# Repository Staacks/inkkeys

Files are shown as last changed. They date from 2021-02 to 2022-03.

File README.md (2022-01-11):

# inkkeys
Details and instructions can be found on https://there.oughta.be/a/macro-keyboard

In contrast to most of my other projects, I decided to put this into its own repository as it is slightly more complex and I am hoping for community contributions.

If you have pull-requests, bug reports or want to contribute new case designs, please do not hesitate to open an issue. For generic discussions, "show and tell" and if you are looking for support for something that is not a problem in the code here, I would recommend [r/thereoughtabe on reddit](https://www.reddit.com/r/thereoughtabe/).

<a href="https://www.buymeacoffee.com/there.oughta.be" target="_blank">Buy Me A Coffee</a>

## Common problems

### Display revision 2
Apparently, the original design used revision 1 of the display, while many newly ordered version are revision 2. There are a few differences and thankfully, [Corky402 made a good list of required changes on Reddit](https://www.reddit.com/r/arduino/comments/l4wxxf/the_hardware_is_assembled_and_passed_all_tests/gqovq1j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). Here is an excerpt of the original post for reference:
>If you want to test your display hooked to a Arduino or Raspberry Pi you need to run examples for the epd2in9_V2 not the epd2in9.
>
>To get this awesome project working there is no need to make any alterations to the PCB, just simply plumb the Waveshare up on the connectors as I describe, not as per Sebastian's original post.
>
>PCB Pin Waveshare wiring loom
>
>+5v Grey
>
>GND Brown
>
>DIN Blue
>
>CLK Yellow
>
>CS Orange
>
>DC Green
>
>RST Purple
>
>BUSY White
>
>In short you are swapping the RST & BUSY lines on the PCB.
>
>Next, go to your Arduino sketch. This is for the hardware-test script. Enable line numbering and go to line 43 which reads -
>
```c
GxEPD2_290 display(/*CS=*/ PIN_CS, /*DC=*/ PIN_DC, /*RST=*/ PIN_RST, /*BUSY=*/ PIN_BUSY);
```
>
>Change this to -

```c
GxEPD2_290_T94 display(/*CS=*/ PIN_CS, /*DC=*/ PIN_DC, /*RST=*/ PIN_RST, /*BUSY=*/ PIN_BUSY);
```

>Then go to settings.h
>
>Lines 2 - 7 need to be altered so change that section of code as follows -
```c
const byte PIN_DIN = 16;
const byte PIN_CLK = 15;
const byte PIN_CS = 19;
const byte PIN_DC = 18;
const byte PIN_RST = 10;
const byte PIN_BUSY = 14;
```
>
>The sketch will then compile and when uploaded to the board you will get the Waveshare drawing all sorts of Austin Powers time machine circles that make your eyes spin! 

## Gallery

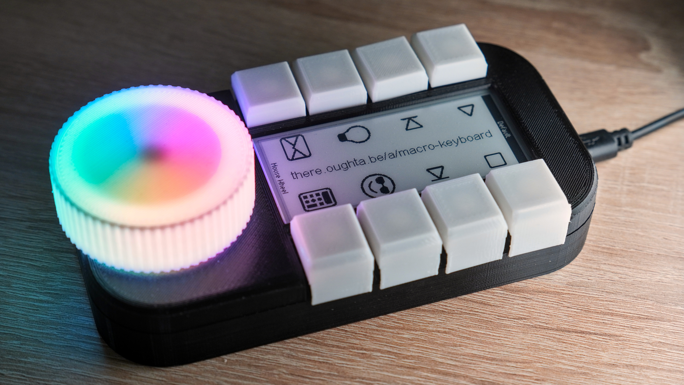
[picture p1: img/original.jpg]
Original design Original design as presented on there.oughta.be with the 3d printing files from this repository.

Original design as presented on there.oughta.be with the 3d printing files from this repository.

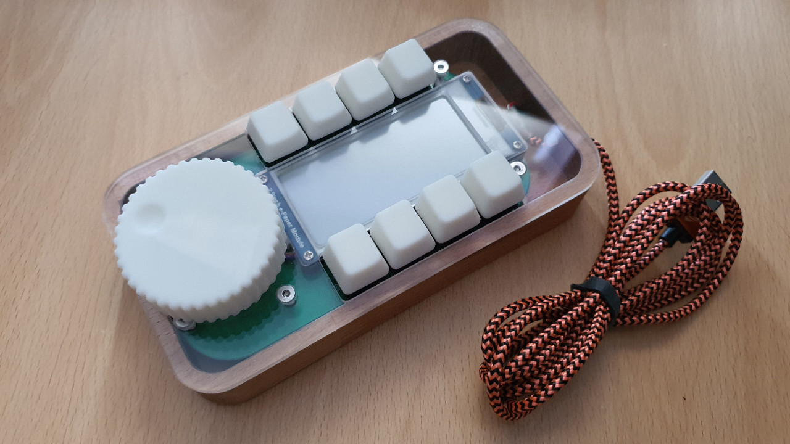
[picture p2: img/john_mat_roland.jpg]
Original design Design by John, Mat and Roland from the UK. The case was CNC milled from beech with a similarly machined clear perspex lid.

Design by John, Mat and Roland from the UK. The case was CNC milled from beech with a similarly machined clear perspex lid. You can find the knob with finger dimple by Roland Irving in the 3dprint folder as know_with_dimple.stl.

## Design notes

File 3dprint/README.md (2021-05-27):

# 3d models

All STLs are based on the same [Blender](https://www.blender.org/) file I used to create the animations in the video. The model in the blend file is based on a 3d model exported from KiCad, which I converted using FreeCAD. So, most of the components are from the KiCad libraries while I got the Pro Micro from the [Spark Fun KiCad Libraries](https://github.com/sparkfun/SparkFun-KiCad-Libraries) combined with a [3d model by Andrew Whitham](https://grabcad.com/library/arduino-pro-micro-1) for the Pro Micro.

The knob version with a finger dimple (know_with_dimple.stl) is by Roland Irving.

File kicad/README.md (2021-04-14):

# Alternative layouts and PCB designs

Modifications by user are linked below:
* [SMD version by dschiedsch](https://github.com/dschiedsch/inkkeys) Similar to the orignal, but LEDs, resistors and capacitors are SMD components.

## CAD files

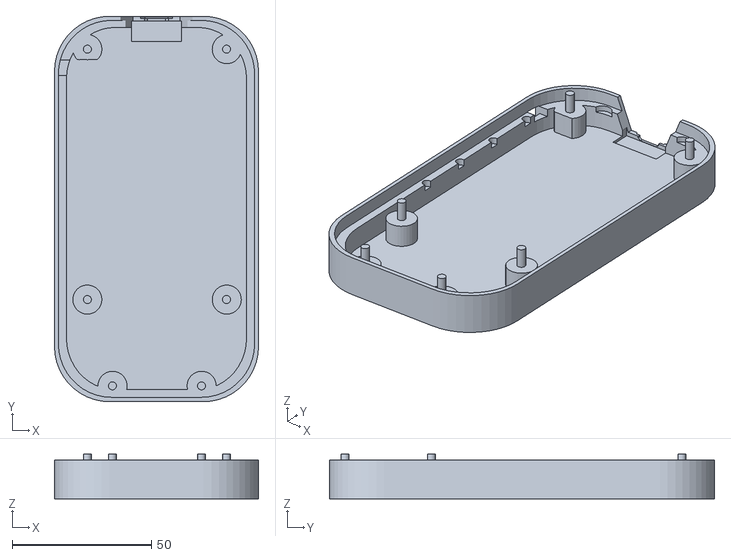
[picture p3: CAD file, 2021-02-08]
3dprint/bottom.stl
73.3 x 138.5 x 16.1

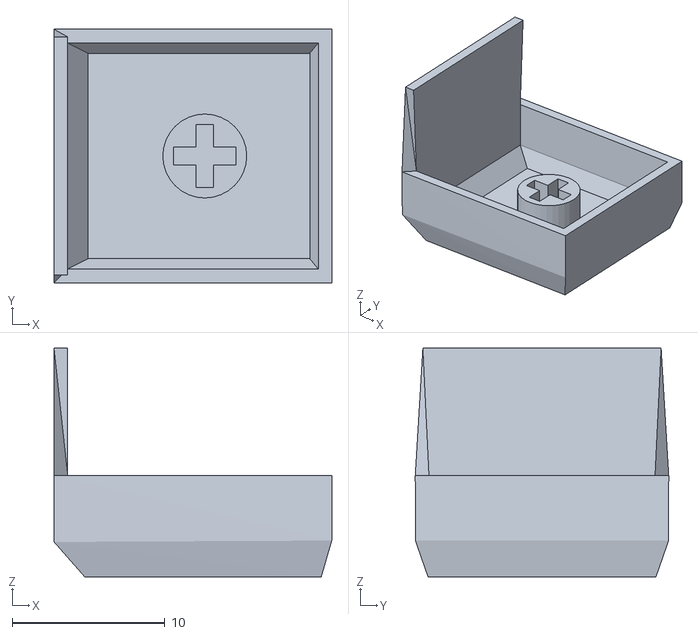
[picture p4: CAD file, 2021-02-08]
3dprint/key.stl
18.2 x 16.6 x 15.0

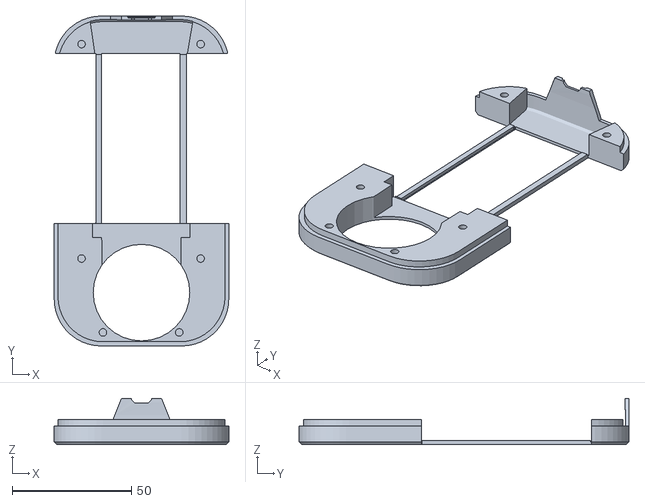
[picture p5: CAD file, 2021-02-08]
3dprint/top.stl
73.3 x 138.5 x 19.4

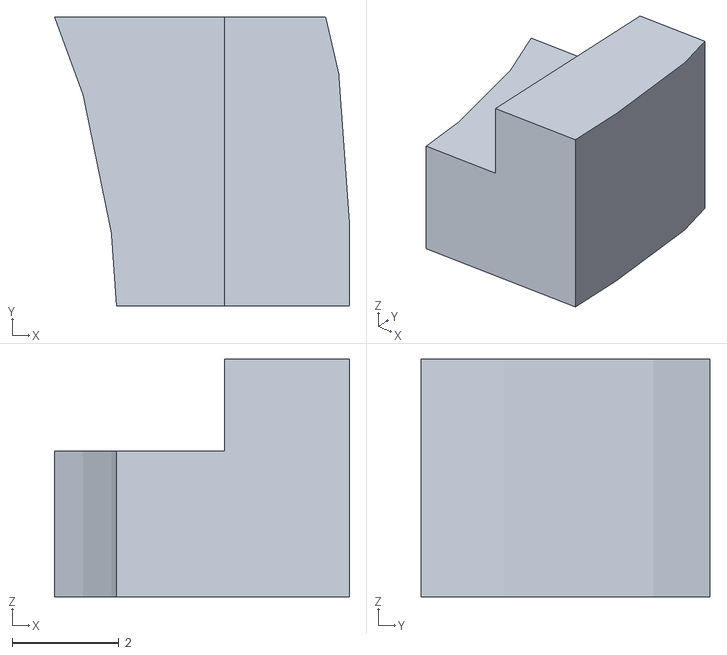
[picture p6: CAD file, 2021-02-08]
3dprint/debug-plug.stl
5.53 x 5.42 x 4.46

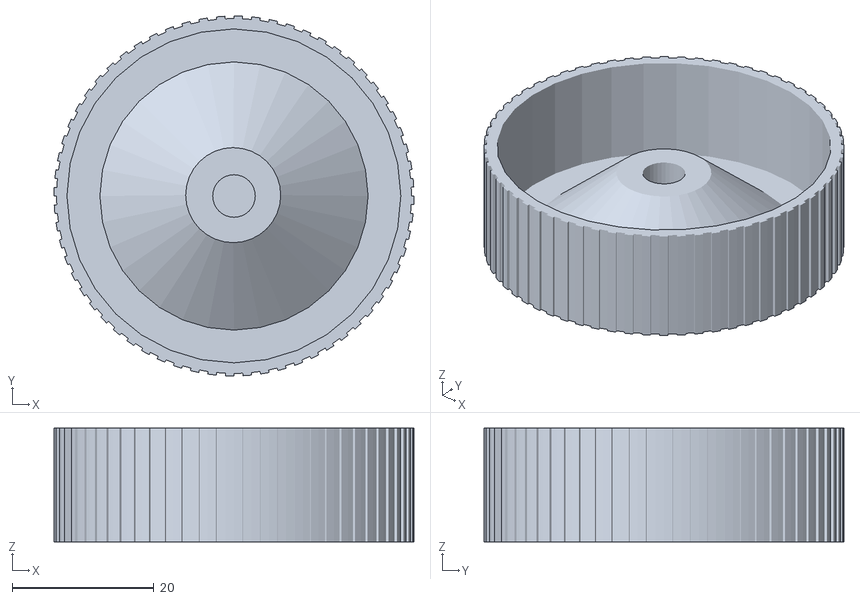
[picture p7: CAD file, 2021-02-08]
3dprint/knob.stl
50.7 x 50.7 x 16.1

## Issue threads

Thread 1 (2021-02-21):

Request: Gerber Files for Other PCB Services?

Extra-Fox, 2021-02-21:
Hi, I am totally digging this project and am eager to try my hand at building one.

Being an absolute hack when it comes to PCB software, would it be possible for you to create some Gerber files of your PCB design? I tried plotting it from KiCAD, but I wasn't getting copper layers that JLCPCB recognized.

Staacks, 2021-02-23:
Hm... Not sure if it will help if I export them. I ordered my PCB from aisler.net where I uploaded the KiCad files, so I have no starting point to export them any differently than you did. Are there any naming conventions from JLCPCB? I am quite sure that I had to rename a layer or two to match the aisler naming conventions, so maybe it is as simple as naming the layers according to their suggestions.

Extra-Fox, 2021-02-23:
Okay, bear with me here because my skill set here barely exists.

But it looks like they were looking for two layers named *.cu. Which didn't appear when I tried plotting from KiCAD (I downloaded and installed it for this)

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

And I was following these instructions here: https://support.jlcpcb.com/article/44-how-to-export-kicad-pcb-to-gerber-files

So if it's simply a naming convention in that case, I'd be happy to go into the files I have locally and change that, however I'd probably need your guidance on the conversion key.

Staacks, 2021-02-23:
Ah, I see. The "F.Cu" and "B.Cu" are just named "Front" and "Back" in my file. And now that I checked it I realize that this was not my idea but I started with a template from Aisler.

You might want to compare the manufacturing tolerances of Aisler and JLCPCB to see if there is something you need to look out for. Since I used the Aisler rules, some distance could be too small for other services, although I would not expect it as there is nothing too fancy about this design.

Extra-Fox, 2021-02-23:
Okay, I'll do that, thank you for the heads up and the guidance.

If anything, I can order from Aisler, but given my location it's generally less expensive for me to use JLCPCB. However, I do want this to work so maybe it's just safer to use Aisler.

Staacks, 2021-02-23:
Yeah, I have no reason to push Aisler - it is just the one I new and happened to use here. This is also the first PCB I designed, but I have ordered from Aisler before in the context of a project from work (in this case the PCB was designed by my PhD student who has done a few PCBs before). To us they are the most local manufacturer (we could literally walk across the border to their headquarter), so I started there without comparing manufacturers a lot.

However, the thing that made me stick with Aisler at least for this first project was that they have a render guarantee. So, I just upload the KiCad file and their system renders a preview of the PCB and they guarantee that the manufactured PCB will match that preview. For me as a beginner this eliminated exactly the "are the gerber files correct?" uncertainty. I will probably try other sources as well on simpler future projects, because Aisler is indeed rather expensive.

Extra-Fox, 2021-02-23:
I totally understand and I didn't get that impression. Local is always good. We have OSHPark which might be considered local, but is still half way across the country from me. Their prices get rather high as well depending on the board.

I've never even designed a board before, just sent those designed by others off to be produced. So, I'm not sure I'm brave enough to take the leap you did, but maybe one day. So far I've just clumsily hand wired any projects without boards.

Extra-Fox, 2021-02-24:
Well, I figured it out. I got it working with OSHPark and with JLCPCB. Unfortunately OSHPark's price was over $70USD so that was a non-starter. JLCPCB was able to do it, with a black circuit board and ENIG-ROHS coating for $35USD shipped.

Staacks, 2021-02-24:
Well, that is not that much cheaper, but it is a rather large PCB.

Extra-Fox, 2021-02-24:
No, probably less than having it made in DE and shipped here, but not a lot less. I'm more familiar with using JLCPCB though so it's a comfort level thing I suppose.

Extra-Fox, 2021-03-16:
It sure is a nice board.
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

Staacks, 2021-03-19:
I really need to try other manufacturers - Just for that black finish :)

x4FF3, 2021-06-11:
my JLCPCB order was 16$ for 5 PCBs :) shipped to germany

WiBla, 2022-01-26:
Hello, I'm also looking forward building my own macropad !

@x4FF3 would you be so kind as to provide the gerber files you used ?
Thanks in advance !

Closed 2021-02-23.

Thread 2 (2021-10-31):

Capacitors for neo pixels

drobertwilcox, 2021-10-31:
Hello Sebastian,

I found your project through a hack a day blog post, https://hackaday.com/2021/02/18/dynamic-macro-keyboard-controls-all-the-things/, and I am certainly interested in trying to build one.  I have not completely reviewed the circuit, but I did see that the RGB neo pixel LED modules do not have a decoupling capacitor.  This could cause flashing, browning out, general misbehaving of the LED device.  I am currently installing ki-cad to look at the circuit design and layout.  I am bringing this up because I was thinking about modifying the layout and adding a string of addressable RGB under the key caps, because more RGB is always better! Though I will have to look at the power consumption of the devices in total to ensure that it stays USB compatible with no need of an external power source. This part may be the part of choice for individual key RGB https://kprepublic.com/products/xd-halo-rgb-light-control-pcb-soft-lighting-light-diffuser-circle-light-for-mechanical-keyboard-cospad-xd60-64-75-84-96-40-68

Staacks, 2021-10-31:
Yes, I definitely forgot those. I am quite new to these designs and learned about this issue after I finished the project. Luckily, I had no issues so far, but as far as I can tell from my research, the cheap THT RGB LEDs in my design are even more susceptible to such issues than the typical WS2812b ones.

Let me know about your project when it is ready. If you intent to share, I will happily link to the improved version in the readme of my repository version or directly add it if you don't want to publish it as a fork yoursef.

drobertwilcox, 2021-10-31:
I am new to GIThub, please excuse me if I don't know the processes that are in place to fork a project.  I will be exploring options for the RGB key switches.  Maybe the key switches with the 4 holes for the LED to pass through would be a better choice for anchoring the key to the board: https://www.amazon.com/Transparent-Switches-Mechanical-Keyboard-Compatible/dp/B07K7LJNLR?th=1 I don't know if the 5mm LED will fit inside.
I will let you know what I come up with, and also I may need some time to learn how to use github.

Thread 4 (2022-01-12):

LED Pin Spacing and Ground Plane

Rudis1261, 2022-01-12:
I order 5 boards from PCBway and I am super happy that they came out really great. But one of the issues I was having is definitely the pin spacing of the LEDs, it's quite a pain. I think most people would be happy to print a 3mm or so ring spacer and rather use 2.54mm pitch, with the legs slightly bent. I kinda trashed one of my boards just because of that issue.

This raised something else, which may need improvement. The ground plane is massive :scream:, my poor little soldering iron could not heat it fast enough to use a wick as suggested to clear out excess solder.

I wonder if the ground plane could have an isolation ring around the circuit to reduce the ground plane, and make it easier to heat up. Basically, all the heat is transferring into that entire PCB plane at the moment.

Not so much as an issue, but a quality of life on both

Staacks, 2022-01-14:
I am happy to add this to the repository if someone tries this modification and confirms that it works.

Regarding the GND plane, I do not particularly recall problems while soldering, but for anyone who is worried about this, there is an easy solution: If you select the ground plane in KiCad and go to its properties, there is an option "pad connections" which is already set to "thermal reliefs". So, at the moment, all pads only use thin spokes to connect to the ground plane to alleviate this exact problem. If you want to reduce the thermal coupling further, you can modify the settings below this to create thinner spokes or increase the clearance. You can also set this individually for each pad than for the entire plane.

Rudis1261, 2022-01-14:
That's awesome thanks Sebastian! I will probably have it made in future
again as the project matures.

I will also definitely try your suggestion next time before I generate the
grbl files.

Cheers,
Rudi

On Fri, Jan 14, 2022 at 1:33 PM Sebastian Staacks ***@***.***>
wrote:

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

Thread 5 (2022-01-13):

Can't seem to get the python app running

Rudis1261, 2022-01-13:
I run windows 10, and it seems it's not quite working as expected. I first ran into an issue where win32gui wasn't available, and resolved that by installing `pip install pywin32`

Then I tried launching it, but next it failed at a pulse audio import in modes.py. Which from what I understand should only be available in linux.

```
Traceback (most recent call last):
  File "./controller.py", line 9, in <module>
    from modes import *          #Definitions of the hotkey functions in different "modes"
  File "C:\Users\Rudi\Documents\Github\inkkeys\python-controller\modes.py", line 23, in <module>
    import pulsectl                                  # Get volume level in Linux, pip3 install pulsectl
  File "C:\Users\Rudi\AppData\Local\Programs\Python\Python37\lib\site-packages\pulsectl\__init__.py", line 4, in <module>
    from . import _pulsectl
  File "C:\Users\Rudi\AppData\Local\Programs\Python\Python37\lib\site-packages\pulsectl\_pulsectl.py", line 684, in <module>
    pa = LibPulse()
  File "C:\Users\Rudi\AppData\Local\Programs\Python\Python37\lib\site-packages\pulsectl\_pulsectl.py", line 636, in __init__
    p = CDLL(ctypes.util.find_library('libpulse') or 'libpulse.so.0')
  File "C:\Users\Rudi\AppData\Local\Programs\Python\Python37\lib\ctypes\__init__.py", line 356, in __init__
    self._handle = _dlopen(self._name, mode)
OSError: [WinError 126] The specified module could not be found
```

I then commented out the pulse audio import which got me to where I am now.

My device is COM20, and when I start it, it does this:
```$ ./controller.py
https://there.oughta.be/a/macro-keyboard
I will try to stay connected. Press Ctrl+c to quit.
Connecting to  COM20 .
Requesting device info...
Header found. Waiting for infos...
End of info received.
Testmode:  False
Number of LEDs:  10
Display width:  128
Display height:  296
Rotation circle steps:  20
Connected to  COM20 .
Error:  <class 'AttributeError'>
I will retry in three seconds...
Connecting to  COM20 .
Serial error:  could not open port 'COM20': PermissionError(13, 'Access is denied.', None, 5)
I will retry in three seconds...
Connecting to  COM20 .
Serial error:  could not open port 'COM20': PermissionError(13, 'Access is denied.', None, 5)
I will retry in three seconds...
Connecting to  COM20 .
Serial error:  could not open port 'COM20': PermissionError(13, 'Access is denied.', None, 5)
I will retry in three seconds...
Connecting to  COM20 .
Serial error:  could not open port 'COM20': PermissionError(13, 'Access is denied.', None, 5)
I will retry in three seconds...
Connecting to  COM20 .
```

Any advice / suggestions would be welcome.

Staacks, 2022-01-16:
Unfortunately, I do not have a Windows machine that I can easily use to test, so I can only offer my experience of a little mistake I sometimes made during development: If you have the Arduino IDE and especially the serial monitor open at the same time, the serial port is already in use and you cannot open it in Python.
If it's not that simple, I would suggest to try open COM20 with a minimal example from pyserial first to narrow down possible reasons.

Rudis1261, 2022-01-17:
I think it's this bit causing the issue: ```Error:  <class 'AttributeError'>``` it connects and gets the info, but after that, I think it's tied up by the process before the failure.

I don't know python's debugger really, otherwise, I would step through the code and debug it. I am assuming it's because of the pulse library methods being called which I had to comment out to get it to even run in the first place. I will try and debug it at some point yeah.

Rudis1261, 2022-01-18:
Bricked my leo, can't continue, so closing the issue.

Staacks, 2022-01-18:
Again, sorry to hear that.

If you manage to get it running again or to anyone else stumbling upon this:
You are right, I missed the first error in the log. Unfortunately, that does not tell much. If you change line 4 of the Python script from "DEBUG = False" to "DEBUG = True", we should see a stack trace, which allows us to understand where this is comming from.

Rudis1261, 2022-01-18:
Will definitely try again once I get more stock of all the parts thanks

amercer86, 2022-01-22:
I think this COM error is a red herring. I was experiencing the exact same issues with my windows install as well. First I needed to disable pulsectl, then I started getting the COM Permission Errors.

I switched DEBUG to True and saw that MQTT was failing to connect (I hadn't tried to configure this yet). I updated the IP to connect to my broker - and the COM errors stopped. I switched back and forth to confirm.

It seems to me like MQTT connection failure is reporting as this COM error.

Closed 2022-01-18.

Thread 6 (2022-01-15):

Example Of Images

Rudis1261, 2022-01-15:
Is there any chance I could get an example of a full image refresh and a partial image refresh?

I am a bit confused and trying to get something usable going in golang, but I need an example of how to flash the whole screen and a partial update. What it would look like in raw serial data would be very useful.

Like a simple example of writing a centered glyph or word, and the steps to draw it :pray:

Staacks, 2022-01-16:
Can you run the Python controller? If so, the easiest way would probably be logging its serial communication, as it would make it quite easy for you to create specific examples that you are interested in.

Rudis1261, 2022-01-17:
It breaks on windows, so doesn't get to that point sadly.

Rudis1261, 2022-01-18:
I bricked my leo last night trying to do a test image with the native library to test. So closing the issue

Staacks, 2022-01-18:
Sorry to hear that. Can't you just reinstall a bootloader with another Microcontroller?

(Also: Why a Leonardo? Were you trying it on a breadboard?)

Rudis1261, 2022-01-18:
I believe the micro pro is just the modern version of the leonardo. Their pinout is the same and everything. At least when I plug one in, its what my arduino recognizes it as.

I got the display to work just before bricking it 🙈🙈 I had one of the images on memory and with a serial command it printed it to screen which finally worked.

And then I accidentally uploaded too large a sketch which bricked it 🙈

Rudis1261, 2022-01-18:
I will try and reinstall the bootloader with an ardiuno as isp. But I doubt it will work, looks like its completely locked up. Oh well serves me well for being impatient

amercer86, 2022-01-22:
I'm also using a Leonardo - it _is_ labeled as a Micro Pro though

Closed 2022-01-18.

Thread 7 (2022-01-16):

inkkeys/python-controller/processchecks.py

s53zo, 2022-01-16:
Hi!
Thanks for making this great project. I will build 6 of the keyboards to help control a radio amateur station.

On a Mac OS, Monterey 12.1 I have a problem with using AppKit. It is installed with pip3 so the OS should be ready.

when processchecks.py is with capital letters like:
from AppKit import NSWorkspace

it doesn't find the AppKit. If I change it to small caps:
from appkit import NSWorkspace

it finds the Appkit but doesn't find NSWorkspace with error:
Traceback (most recent call last):
  File "/Users/simon/Downloads/inkkeys/python-controller/controller.py", line 7, in <module>
    from processchecks import *  #Functions to check for active processes and windows
  File "/Users/simon/Downloads/inkkeys/python-controller/processchecks.py", line 13, in <module>
    from appkit import NSWorkspace
ImportError: cannot import name 'NSWorkspace' from 'appkit' (/usr/local/lib/python3.9/site-packages/appkit/__init__.py)

Any idea and help please?

Staacks, 2022-01-16:
Unfortunately, I cannot try it myself on a Mac and this part of the code is from an example without actual testing (as mentioned in the article). However, the fact that for you it is lower-case is quite suspicious and it seems like you are trying to load NSWorkspace from a different package.
I found this: https://stackoverflow.com/questions/53808723/importerror-no-module-named-appkit-after-installing-appkit-and-pyobjc
Could this be your problem, too?

s53zo, 2022-01-17:
Good call, exactly as you foresaw.

pip3 uninstall AppKit
pip3 install --upgrade --force-reinstall PyObjC PyObjC-core

solved the issue.

Closed 2022-01-17.

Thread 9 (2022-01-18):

Arduino micro pro usbc

Rudis1261, 2022-01-18:
I think it should be a recommendation to use a micro pro with a USB-C connector. I have broken more micro USB off these than I care to mention 🙈

Rudis1261, 2022-01-18:
Sorry using the issues as like a feature request form 🤣🙈

Rudis1261, 2022-01-18:
Like this I ordered:

ZAR 70.23  20％ Off | ATmega32U4 3.3V 8Mhz Pro Micro 5V 16MHz Board Module MINI/ MICRO/Type-C USB For Arduino/Leonardo Controller Replace Pro
https://a.aliexpress.com/_mNFnc0C

lucas-fern, 2022-02-22:
Pro micro with USB-C works without any changes to the code. The only modification I had to make was to the case, since the pro micro with USB-C was a little bit longer than with micro-USB.

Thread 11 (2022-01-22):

Question regarding resistor cluster

Rudis1261, 2022-01-22:
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

I am curious what these resistors are used for, mind sharing some insight? I may or may not be busy with a variation of the board, and I can't say I have played with an encoder wheel before to understand why it's needed.

Rudis1261, 2022-01-22:
Are they serving as a voltage devider?

Staacks, 2022-01-22:
No, to my understanding, it is a pull-up and a low-pass for debouncing. I have to admit that I found this as one of the most common ways to hook up a rotary encoder and I did not much testing, so there might be details I am missing myself, but I think I have a good idea of what it does. First of all, we should look at the schematic for a more intuitive layout:
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
(I removed the irrelevant parts.)

You will notice that the encoder is only connected to ground and does not have any positive connection. S2 is the push button on the encoder and if you press it, it closes the connection to S1, which is connected to ground. In order to have a proper state while it is not pressed, it needs a pull-up resistor, which is no problem as we use the internal pull-up of the Pro Micro on pin 20.

For the rotation, the situation is similar. contacts A and B will alternate between being open or connected to C, which in turn is connected to ground. So, for the open state, we need a pull-up. In a perfect world, we could connect A and B directly to pins 1 and 2 on the Pro Micro and also use internal pull-ups. Unfortunately, any switch might bounce (quickly alternate between open and closed before eventually settling on a final state).

For the normal keys and the push button, this is not that much of a problem, because we just lazily read them in a loop and bouncing is usually faster than our read-out anyways. The rest can be done with a debounce in software to avoid multiple triggers within a certain time frame. If it wasn't a macro keyboard but something with very rapid inputs, this might not be enough, but for a macro keyboard, this should be fine.

On the rotary encoder however, we might want to quickly turn it for fast scrolling, so I use a fast encoder library which uses interrupts on both pins that are connected to the encoder (as I said, I never tested it without, so it might be fast enough without interrupts). If a bounce occurs now, the interrupts will be fast enough to trigger multiple times and as the relative switches of both inputs might even be identical to a full encoding cycle (in contrast to a key, where there are only two states), we really need to avoid this and it becomes really hard to detect this in software. So, we debounce in hardware.

To my understanding, C1 and R4 as well as C2 and R3 act as a simple low pass. Thinking about it now, intuitively I would have placed the capacitors to ground between the resistors and the GPIO pins, but I don't think that this makes much of a difference.

Now, that we have placed those resistors between pin A and B and the GPIOs, using the internal pull-ups would be quite pointless. They would only permanently the GPIOs to +5V as the encoder would not be able to pull it back to ground through that 10k resistor. So, instead, we need to add external pull-ups before that, which is R1 and R2.

Hope, you could follow - and I hope that my own interpretation is correct :)

Rudis1261, 2022-01-23:
That is great thanks for the explanation, that helps a lot!  😃

Closed 2022-01-23.

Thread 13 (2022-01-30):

PCB give away if you cover my costs

Helicon007, 2022-01-30:
I ordered a amount of 10 PCBs because one piece is obviously not worth it. So I can share the remaining 9 PCBs if you cover my basics costs.

I'll send you one PCB each by postal mail without warranty it will arrive the destination. 2€ + postage fee. One mail is less than 40g.
Payment via Paypal.

Please contact me if you desire a brand new green PCB for the macro keyboard project.

btw: I have very good experience with JLCPCB from China - no advertisement but this was not my fist order and price/quality is very good.

Staacks, 2022-01-30:
Good idea to combine PCB orders, so I just shared this issue on Twitter. (Not sure if the issue tracker is the best place for it, though.)

ondras, 2022-01-30:
Hi @Helicon007,

I would be interested in the PCB - or perhaps two, if the postage does not increase dramatically. I am located in the Czech Republic. Is it okay to contact you this way? Can we arrange a shipment?

Helicon007, 2022-01-31:
> Hi @Helicon007,
>
> I would be interested in the PCB - or perhaps two, if the postage does not increase dramatically. I am located in the Czech Republic. Is it okay to contact you this way? Can we arrange a shipment?

Hi Ondras,
I sent you an eMail to handle this, hope it's not in your spam.
Regards, Helicon

marengo560, 2022-02-01:
Hi @Helicon007,

I would also be interested in a couple of them if you still have them.

Regards,

Rafael

Helicon007, 2022-02-01:
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

Sure, contact me via helicon@gmx.de
Let me know how many and what address, I‘ll check the postage then.

Regards, Helicon

Helicon007, 2022-02-02:
The PCB's are on their way and I'm glad I didn't waste them. I just hope they receive their destination undamaged. If not, let me know please.

Have fun, Helicon

marengo560, 2022-02-08:
Hi @Helicon007,

Just to let you know I got the PCBs and they arrived safe and sound! Thanks 👍

Regards,

Rafael

Closed 2022-02-02.

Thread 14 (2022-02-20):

e-Paper Module not Performing Parital Refresh

lucas-fern, 2022-02-20:
I've got the device programmed and working on Windows 10, but haven't been able to get the display to perform a partial refresh at any point. I have the v2 of the display and have made the changes to the Arduino code as specified in the readme.

Not sure what the intended behaviour is, but the hardware demo file does display a static image, and then clears.

In the python controller however the functionality of the different keys is working, but the only time I can get an image on the screen is by pressing button 8 to toggle the demo display. I realised that this function makes a call to `updateDisplay` with `fullRefresh=True`, so I made that the default in the `updateDisplay` function and now all the screens display correctly, but only after a lengthy full refresh.

Has anyone else encountered this issue? Or any suggestions for what to try to resolve it? If any additional info would be useful to identify the issue let me know and I'll try to provide it ASAP.

Staacks, 2022-02-21:
Sounds like this one discussed over at Reddit:
https://www.reddit.com/r/thereoughtabe/comments/s9sgox/inkkey_display_wont_update/

Is there something in there, that solves it for you?

lucas-fern, 2022-02-22:
Yep, amazing. Made all the changes suggested in that thread and partial updates are working now.

Cheers!

Closed 2022-02-22.

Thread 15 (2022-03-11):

Keycap model source?

ondras, 2022-03-11:
Hi,

I am trying to build this cool keypad. I got most of the stuff working okay, but I failed at keycaps: I managed to print them in PETG without issues, but they do not fit. The cross-shaped hole is too small (using typical Gateron switches).

I would like to fix this, but I need some source 3d model to work with. I do not have Blender nor KiCad (never used these). I am experienced with OpenSCAD and I suppose I can learn some other CAD tools as well, provided I can get the source model.

The documentation states that 3d models were taken from a KiCad component library. Can you please provide some more specific instructions/links for that?

Thanks,
Ondrej Zara

Staacks, 2022-03-13:
Sorry, the files in the repository is all I got. I design those models directly in Blender - not because it is a good tool for technical designs, but it is the tool I am familiar with. The downside is that it is difficult to do "non-destructive" modelling and at some point one often has to apply modifiers. I could not find a blend file with the original modifiers, so the mesh is all I have got (although it is pretty much just a boolean combination of the keycap, a cylinder and an extruded cross - it does not even have a concave top).

The 3d models from the KiCad component library are for the electronics. KiCad has a tool to import 3d models for most common components: https://kicad.github.io/packages3d/ - but that is probably not what you are looking for.

ondras, 2022-03-13:
No problem. I found https://www.thingiverse.com/thing:417509 in the meantime and I am 3d-printing eight of these right now. They come with OpenSCAD source, so I enlarged the cross-shaped hole and the fit is perfect now.

Staacks, 2022-03-13:
Just a head-up: The spacing between the keys is a bit smaller than usual to fit four of them next to the display. Not sure if that's an issue with that round model.

ondras, 2022-03-13:
I had to shrink them. The spacing is an issue indeed: as a custom keyboard fan, I have quite a number of spare (regular) keycaps lying around. None of them fit, the PCB is too crowded. The only way is to 3d-print.

Staacks, 2022-03-13:
Jepp, unfortunately, the normal spacing spreads the keys beyond the length of the display. (But I also have to admit that I did not check the specs when designing the PCB.)

Closed 2022-03-13.

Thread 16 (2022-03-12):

Display not supporting partial updates?

ondras, 2022-03-12:
Hi,

I built the whole keypad, but I am starting to think that my e-ink display is not supporting partial updates. I am opening this issue to organize my thoughts and seek advice.

I have a second revision of the display, so I adjusted the wiring, constants (settings.h) and constructor (`GxEPD2_290_T94`) according to https://www.reddit.com/r/arduino/comments/l4wxxf/the_hardware_is_assembled_and_passed_all_tests/gqovq1j. I did this both in the hardware-test sketch as well as the main inkkeys sketch.

I tried:

  1) the hardware test sketch. This one works flawlessly, shows circle patterns. I am not sure whether this uses partial updates or not.

  2) the regular inkkeys sketch. The serial protocol works. I launched the python script and loaded the `ModeGimp()` mode. The display remained blank/white. Keys are working according to the Gimp mode.

  3) I then connected to the keypad via serial and issues the `R f` command. Magically, everything (icons) appeared on screen.

To further debug the issue, I restarted the keypad, did nothing Python-related, opened the serial terminal and issued:

```
D 50 50 8 2 <enter>
AA <enter>
R f <enter>
```

This worked: two small rows with several black bits appeared. However, when I did the same with partial refresh, nothing appeared:

```
D 50 50 8 2 <enter>
AA <enter>
R p <enter>
```

Finally, once I issued `R f`, everything that has been previously sent (and failed to partially update) appeared.

This is what I bought: https://www.aliexpress.com/item/32811510579.html

Do you think this can be solved software-wise? Or shall I contact the seller? I would be happy for any comments/suggestions.

ondras, 2022-03-12:
Update: just found out that there is another class, `GxEPD2_290_T94_V2`, that might work better with my Display. Will try that and report.

ondras, 2022-03-12:
The `_V2` class fixes the issue! Closing this with a PR to mention these new classes in the Arduino source code: https://github.com/Staacks/inkkeys/pull/17

ondras, 2022-03-12:
It is still problematic, unfortunately.

This happens when I press the jog wheel in the Gimp mode:
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

Note that the "tool size" label has been overwritten by the new (probably "Tool opacity") text only partially. This is definitely because of the partial refresh; issuing a `R f` fixes the screen.

Looks like that during partial update,
  1) black works (previously white pixels are set to black),
  2) white does not (previously black pixels remain black)

Moreover, based on my experience, the whole flow regarding partial updates and double data streaming (as described in https://there.oughta.be/a/macro-keyboard#the-arduino-code) is not really working as expected. After a fresh reboot, I tried this:

```
D 0 0 8 8 <enter>
@@@@@@@@ <enter>
R p <enter>
```

This performed a correct partial update. However, I then sent another `R p` (without re-sending the image data) and nothing happened. I sent another `R f`, the screen blinked and the pattern in the top left corner persisted. In other words, I am unable to reproduce the case "missing partial data in the backbuffer".

Staacks, 2022-03-13:
Unfortunately, I cannot try any of this as I have a rev 1 display (very unfortunate as it seems that I received older stock while most other people have the newer version and therefore some compatibility issues). But your description indeed sounds like your version of the display updates the backbuffer on its own. Still, I think that resending the data should only result in unnecessary communication overhead, but I would not expect visible consequences.

Still, if you want to try disabling the second data submission in the Python code, you just need to comment `self.resendImageData()` in line 173 of "device.py". You can also try commenting the next line, but that should only turn off the power to the display ("R o") - but who knows what that does on the new revision.

ondras, 2022-03-13:
> Still, if you want to try disabling the second data submission in the Python code, you just need to comment `self.resendImageData()` in line 173 of "device.py".

I think that the re-sending is not doing anything harmful in my case. I was doing some experiments using the serial protocol only, namely:

```
D 0 0 8 8
<white/black data>
R f
```

and then:

```
D 0 0 8 8
<black/white data>
R p
```

...and I ended with a black square. In other words, partial update only renders black pixels. I am unable to switch a black pixel to white via a partial update.

(Actually: those black pixels that should become white **do** happen to change a bit, to a less-dark shade of gray. But they still remain much more "black" than "white". This can be seen in the photo posted above as well: the original text is present, but in a tiny bit lighter shade of gray when compared to the overwriting text.)

Staacks, 2022-03-13:
> Actually: those black pixels that should become white **do** happen to change a bit, to a less-dark shade of gray. But they still remain much more "black" than "white". This can be seen in the photo posted above as well: the original text is present, but in a tiny bit lighter shade of gray when compared to the overwriting text.

That does not sound like a logic problem but an electronic one...? Maybe you should test the display with one of Waveshare's demos.

ondras, 2022-03-13:
Perhaps. Honestly, I am kind of "over the limit" for this project, spending waaay more time and energy on it than I initially thought. My use case is somewhat reduced (only one "mode"), so I am going to stick with one (initial) full display update and call it a day.

Staacks, 2022-03-13:
Understandable. I will keep this issue open for a while. Maybe there will be feedback by users with the same display revision. But so far others only had to use the other class and switch two connectors as described in the readme (https://github.com/Staacks/inkkeys#display-revision-2).

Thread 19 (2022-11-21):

OSError: cannot open resource

Yersi88, 2022-11-21:
**I get this error when I try to run the python script:**
```
Connecting to  /dev/ttyACM2 .
Requesting device info...
Sending: I
Received: Inkkeys
Header found. Waiting for infos...
Received: TEST 0
Received: N_LED 12
Received: DISP_W 128
Received: DISP_H 296
Received: ROT_CIRCLE_STEPS 20
Received: Done
End of info received.
Testmode:  False
Number of LEDs:  12
Display width:  128
Display height:  296
Rotation circle steps:  20
Connected to  /dev/ttyACM2 .
Active window: Navigator
Traceback (most recent call last):
  File "/home/marius/Downloads/inkkeys-main/python-controller/controller.py", line 110, in tryUsingPort
    work()  #Success, enter main loop
  File "/home/marius/Downloads/inkkeys-main/python-controller/controller.py", line 78, in work
    mode.activate(device)       # ...and call its activate function
  File "/home/marius/Downloads/inkkeys-main/python-controller/modes.py", line 206, in activate
    device.sendTextFor("title", "Default", inverted=True) #Title
  File "/home/marius/Downloads/inkkeys-main/python-controller/inkkeys/device.py", line 207, in sendTextFor
    font1 = ImageFont.truetype("font/Munro.ttf", 10)
  File "/usr/lib/python3.10/site-packages/PIL/ImageFont.py", line 976, in truetype
    return freetype(font)
  File "/usr/lib/python3.10/site-packages/PIL/ImageFont.py", line 973, in freetype
    return FreeTypeFont(font, size, index, encoding, layout_engine)
  File "/usr/lib/python3.10/site-packages/PIL/ImageFont.py", line 249, in __init__
    self.font = core.getfont(
OSError: cannot open resource

Error:  <class 'OSError'>
I will retry in three seconds...
```

**The error changes when terminal is in focus:**
```
Connecting to  /dev/ttyACM2 .
Requesting device info...
Sending: I
Received: Inkkeys
Header found. Waiting for infos...
Received: TEST 0
Received: N_LED 12
Received: DISP_W 128
Received: DISP_H 296
Received: ROT_CIRCLE_STEPS 20
Received: Done
End of info received.
Testmode:  False
Number of LEDs:  12
Display width:  128
Display height:  296
Rotation circle steps:  20
Connected to  /dev/ttyACM2 .
Could not get active window:  <class 'Xlib.error.BadWindow'>
Traceback (most recent call last):
  File "/home/marius/Downloads/inkkeys-main/python-controller/controller.py", line 110, in tryUsingPort
    work()  #Success, enter main loop
  File "/home/marius/Downloads/inkkeys-main/python-controller/controller.py", line 72, in work
    if ("process" in i and i["process"] in processes) or ("activeWindow" in i and i["activeWindow"].match(activeWindow)) or not ("process" in i or "activeWindow" in i):
UnboundLocalError: local variable 'activeWindow' referenced before assignment

Error:  <class 'UnboundLocalError'>
I will retry in three seconds...
```

I had it working few times so I'm not sure what might be causing this error, it seemingly appears out of nowhere. Any idea what might be causing this?

Staacks, 2022-11-21:
Looks like the font cannot be loaded. Simple first thought: Could it be that you are launching the script from a different directory? The fonts are given as a relative path, so it breaks if you call the Python script from somewhere else.

Yersi88, 2022-11-22:
Oh yes, that was indeed the case. Thank you!

Closed 2022-11-22.

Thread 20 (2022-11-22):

Spare PCBs for sale (cheap)

Yersi88, 2022-11-22:
Hi,

I have 4 more PCBs here that I don't need, they are quite pretty with black solder mask and white silkscreen. Price £4 + postage (should be cheap, fits in letter)

Yersi88, 2023-03-11:
> Hello, how much would it cost to ship to US

£4

dpoulson, 2024-01-17:
Don't suppose you have any left? Would save me getting some more made (I'm in the UK).

If not, might be worth closing this issue so you don't get hassled. :)

Helicon007, 2024-01-20:
I do have one left if you still need one. It'f for free, just cover the post stamp costs Germany to UK.

dpoulson, 2024-01-20:
Fantastic. Sure, let me know how much and your paypal address and I'll send some money over.

Should be able to see my email on my profile, rather than putting it in a random issue. ;)

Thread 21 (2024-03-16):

Serial error - Permission denied when accessing COM port and script silently exiting on Windows

MrEggy, 2024-03-16:
I am trying to get the Python controller running on a Windows machine.  when I run controller.py it appears to connect to the keypad successfully.  It retrieves the info from the keypad.  However when it enters the main loop I get the following error:

Error:  <class 'AttributeError'>
I will retry in three seconds...
Connecting to COM6 .
Serial error:  could not open port 'COM6': PermissionError(13, 'Access is denied.', None, 5)

If I enable debug mode I get the following traceback:

Traceback (most recent call last):
  File "D:\Downloads\DIY\Macro Keypad\inkkeys-main\python-controller\controller.py", line 110, in tryUsingPort
    work()  #Success, enter main loop
    ^^^^^^
  File "D:\Downloads\DIY\Macro Keypad\inkkeys-main\python-controller\controller.py", line 85, in work
    pollInterval = mode.poll(device)
                   ^^^^^^^^^
AttributeError: 'NoneType' object has no attribute 'poll'

Any assistance that you can offer would be appreciated.

MrEggy, 2024-03-18:
I believe this access denied error may in fact be spurious and actually caused by another error as indicated in Issue #5.  I believe it is caused by mqtt connection failing.  Then the serial connection subsequently fails.  If I disable the mqtt code the script runs for a little while.  It sends some keyboard mapping commands.  Which are successfully received by the keyboard.  Then the script exits with no exception.  Any advice on how to get this working on Windows would be greatly appreciated.  Likewise if anyone has some working code I would be very appreciative.

Staacks, 2024-03-19:
I am afraid that I will not be of much help with Windows-specific problems and especially how to set up Python on Windows (in my Linux world, installing Python is a one-liner).
However, if mode is None I would guess that you have entirely removed the fallback mode from the modes list. So, when none of the other modes feels "responsible" it will not default to the ModeFallback in the list. I have not looked into my own code for a while, but I think you need to remove the last parameter of the last entry in the "modes" list so it will always be used if the previous modes do not match.

MrEggy, 2024-03-20:
Thanks Sebastian.  I have just got to the bottom of this problem.  The permission error on the COM port is indeed spurious.  Whenever another error occurs it will generate this error.  Usually the root cause of the problem can be found by enabling debug mode.
Whilst I probably should have opened another issue for this.  The other issue that I reported where the script appears to run.  It communicates with the keyboard.  But then silently exits is caused by the following.
It appears that the getsize() method has been removed from Pillow in versions 10.0.0 or greater.  This will generate the following error.

AttributeError: 'FreeTypeFont' object has no attribute 'getsize'

The suggested solution is to downgrade to Pillow 9.5.0.  However it appears that Pillow 9.5.0 has a bug where it will just silently exit when this method is called.  I tried downgrading further however anything less than 9.5.0 is not compatible with Python 3.12.  So I was stuck.
The solution is to install Pillow version >= 10.0.0  As getsize() is missing you will need to replace the following lines in device.py.

Replace line 208:
wt1, ht1 = font1.getsize(text);

with:
x1, y1, wt1, ht1 = font1.getbbox(text);

Replace line 210:
wt2, ht2 = font2.getsize_multiline(subtext);

with:
 x2, y2, wt2, ht2 = font2.getbbox(subtext);

Staacks, 2024-03-20:
Reopening as it is not yet fixed in the repo - as a reminder for me to fix it and so others who might run into it can find it easily.

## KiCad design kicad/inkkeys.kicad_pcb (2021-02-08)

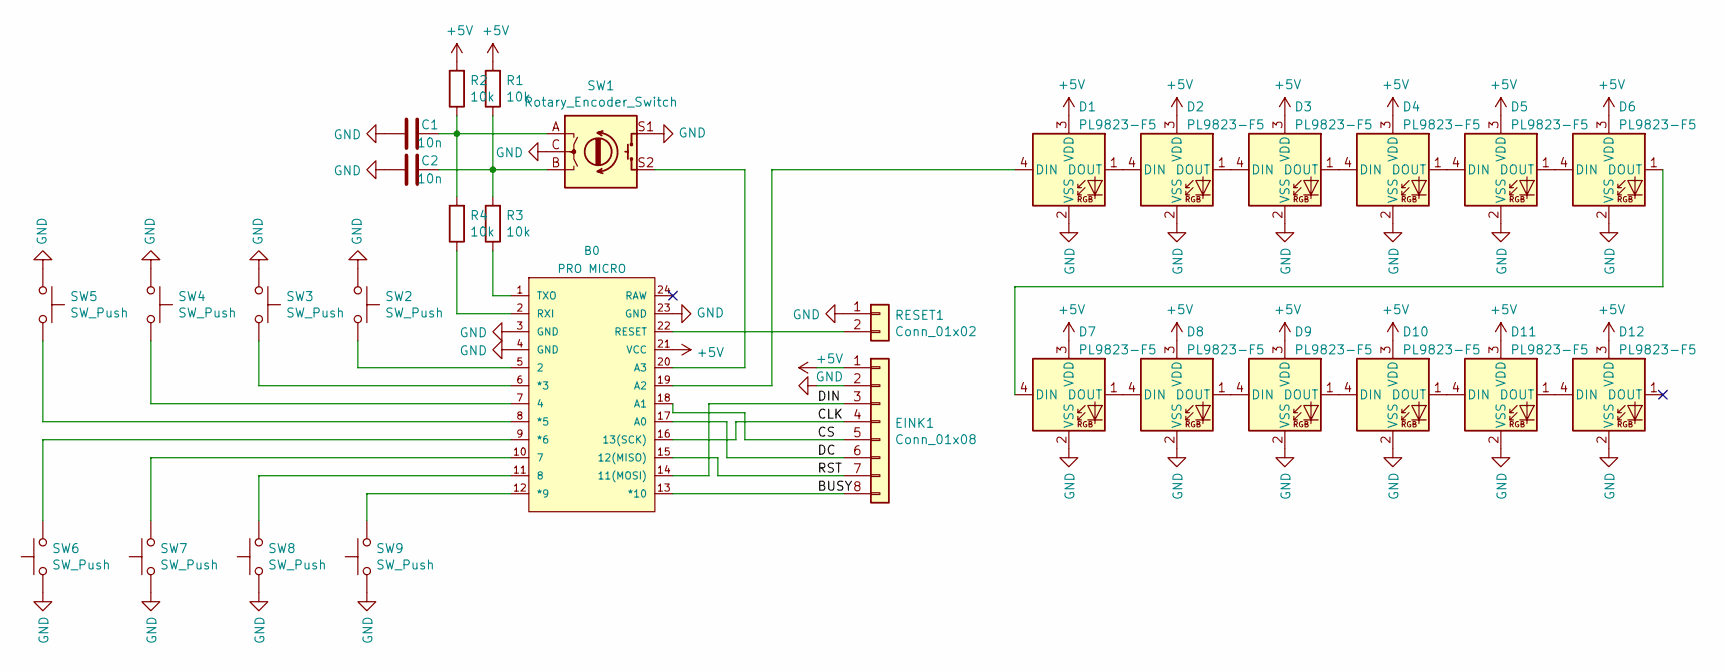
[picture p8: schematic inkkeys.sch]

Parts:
B0: PRO MICRO; SPARKFUN_PRO_MICRO
C1, C2: 10n; C_Disc_D5.0mm_W2.5mm_P5.00mm
D1, D2, D3, D4, D5, D6, D7, D8, D9, D10, D11, D12: PL9823-F5; LED_D5.0mm-4_RGB
EINK1: Conn_01x08; PinHeader_1x08_P2.54mm_Vertical
R1, R2, R3, R4: 10k; R_Axial_DIN0207_L6.3mm_D2.5mm_P10.16mm_Horizontal
RESET1: Conn_01x02; PinHeader_1x02_P2.54mm_Vertical
SW1: Rotary_Encoder_Switch; RotaryEncoder_Alps_EC11E-Switch_Vertical_H20mm
SW2, SW3, SW4, SW5, SW6, SW7, SW8, SW9: SW_Push; SW_Cherry_MX_1.00u_PCB

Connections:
+5V: B0.21 (VCC), D1.3 (VDD), D2.3 (VDD), D3.3 (VDD), D4.3 (VDD), D5.3 (VDD), D6.3 (VDD), D7.3 (VDD), D8.3 (VDD), D9.3 (VDD), D10.3 (VDD), D11.3 (VDD), D12.3 (VDD), EINK1.1, R1.2, R2.2; also elsewhere on the board
/BUSY: B0.13 (*10), EINK1.8; also elsewhere on the board
/CLK: B0.16 (13(SCK)), EINK1.4; also elsewhere on the board
/CS: B0.18 (A1), EINK1.5; also elsewhere on the board
/DC: B0.17 (A0), EINK1.6; also elsewhere on the board
/DIN: B0.14 (11(MOSI)), EINK1.3; also elsewhere on the board
/RST: B0.15 (12(MISO)), EINK1.7; also elsewhere on the board
GND: B0.3 (GND), B0.4 (GND), B0.23 (GND), C1.2, C2.2, D1.2 (VSS), D2.2 (VSS), D3.2 (VSS), D4.2 (VSS), D5.2 (VSS), D6.2 (VSS), D7.2 (VSS), D8.2 (VSS), D9.2 (VSS), D10.2 (VSS), D11.2 (VSS), D12.2 (VSS), EINK1.2, RESET1.1, SW1.C, SW1.S1, SW2.1, SW3.1, SW4.1, SW5.1, SW6.1, SW7.1, SW8.1, SW9.1; also elsewhere on the board
unnamed: B0.1 (TXO), R3.1
unnamed: B0.2 (RXI), R4.1
unnamed: B0.5 (2), SW2.2
unnamed: B0.6 (*3), SW3.2
unnamed: B0.7 (4), SW4.2
unnamed: B0.8 (*5), SW5.2
unnamed: B0.9 (*6), SW6.2
unnamed: B0.10 (7), SW7.2
unnamed: B0.11 (8), SW8.2
unnamed: B0.12 (*9), SW9.2
unnamed: B0.19 (A2), D1.4 (DIN)
unnamed: B0.20 (A3), SW1.S2
unnamed 20: B0.22 (RESET), RESET1.2; also elsewhere on the board
unnamed: C1.1, R2.1, R4.2, SW1.A
unnamed: C2.1, R1.1, R3.2, SW1.B
unnamed: D1.1 (DOUT), D2.4 (DIN)
unnamed: D2.1 (DOUT), D3.4 (DIN)
unnamed: D3.1 (DOUT), D4.4 (DIN)
unnamed: D4.1 (DOUT), D5.4 (DIN)
unnamed: D5.1 (DOUT), D6.4 (DIN)
unnamed: D6.1 (DOUT), D7.4 (DIN)
unnamed: D7.1 (DOUT), D8.4 (DIN)
unnamed: D8.1 (DOUT), D9.4 (DIN)
unnamed: D10.1 (DOUT), D11.4 (DIN)
unnamed: D9.1 (DOUT), D10.4 (DIN)
unnamed: D11.1 (DOUT), D12.4 (DIN)

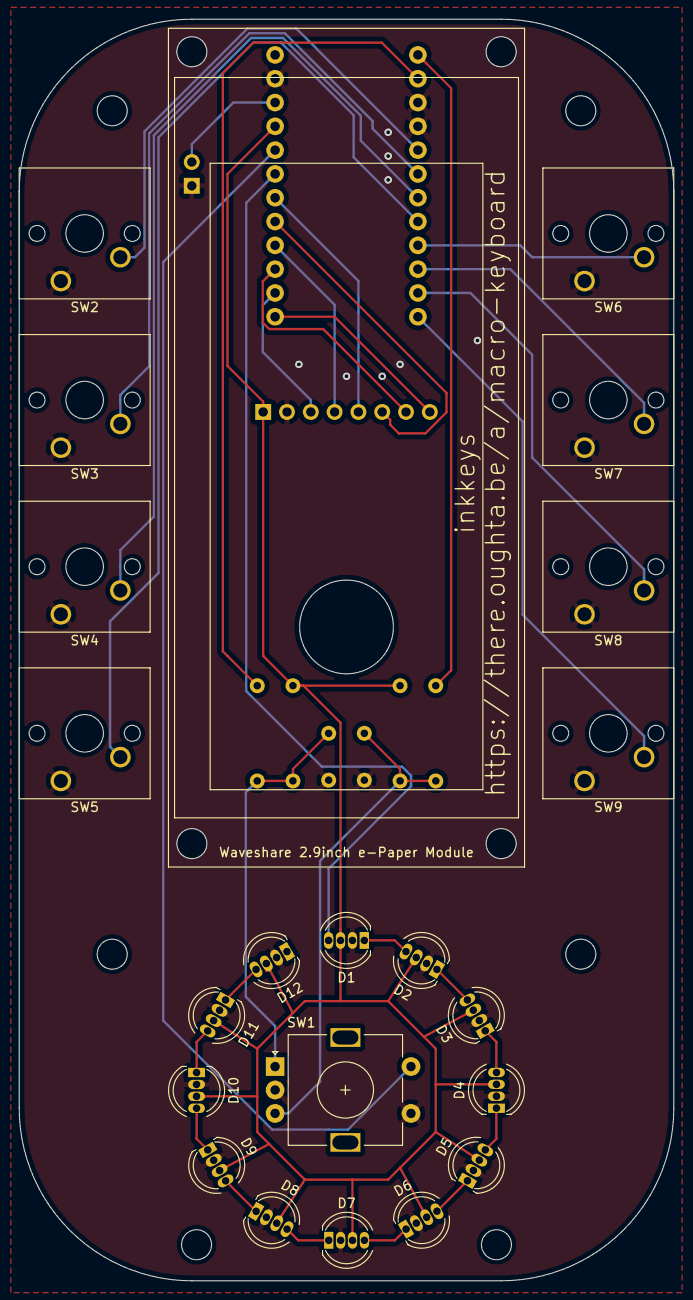
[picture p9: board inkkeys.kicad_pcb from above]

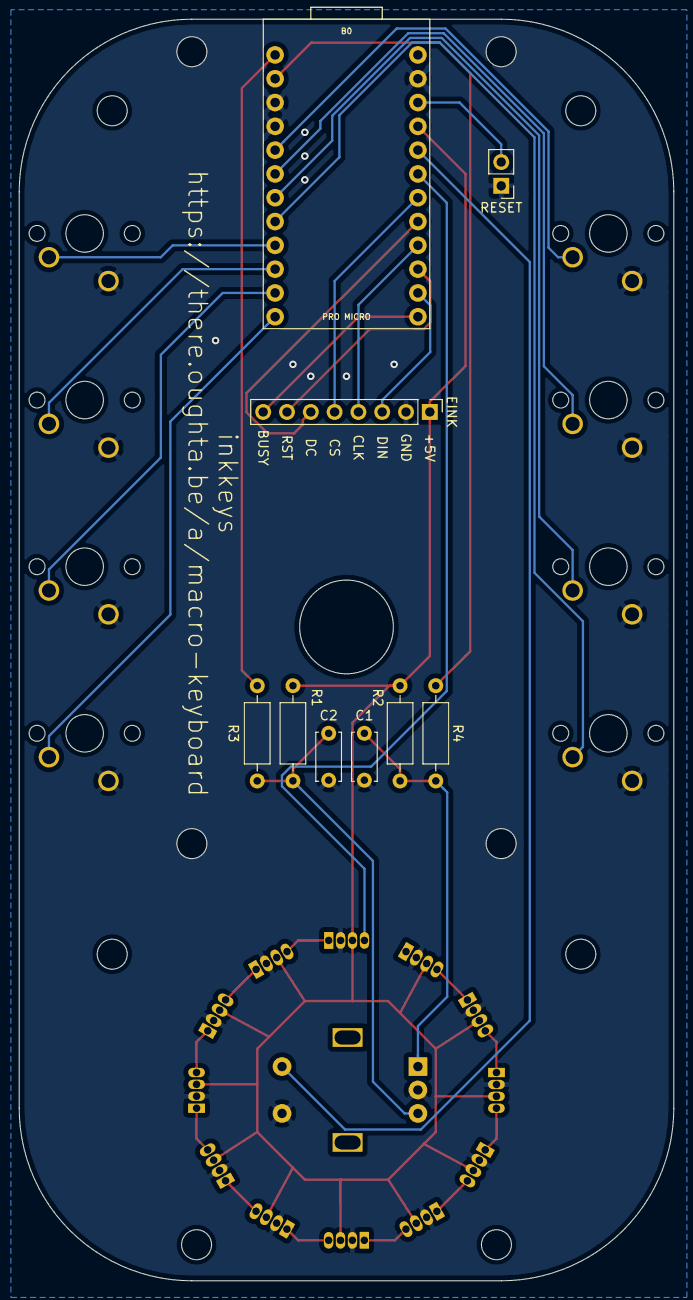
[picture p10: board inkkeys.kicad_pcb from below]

Board: 2 copper layers, 69.9 x 134.6 mm, 30 parts (9 on the bottom side), 34 nets.

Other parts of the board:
EINK: Conn_01x08; PinHeader_1x08_P2.54mm_Vertical
RESET: Conn_01x02; PinHeader_1x02_P2.54mm_Vertical

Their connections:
+5V: EINK.1; also elsewhere on the board
/BUSY: EINK.8; also elsewhere on the board
/CLK: EINK.4; also elsewhere on the board
/CS: EINK.5; also elsewhere on the board
/DC: EINK.6; also elsewhere on the board
/DIN: EINK.3; also elsewhere on the board
/RST: EINK.7; also elsewhere on the board
GND: EINK.2, RESET.1; also elsewhere on the board
unnamed 20: RESET.2; also elsewhere on the board

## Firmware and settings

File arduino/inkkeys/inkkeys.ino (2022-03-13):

/*
 * E-Ink adaptive macro keyboard
 * See https://there.oughta.be/a/macro-keyboard
 *
 * This is the main code which acts as a HID keyboard while
 * allowing to be controlled through a serial interface.
 */

#include "settings.h"           //Customize your settings in settings.h!

#include "eventsequence.h"      //Structure and constants to define the sequence of events assigned to different buttons

#include <HID-Project.h>        //HID (Keyboard/Mouse etc.)
#include <Encoder.h>            //Rotary Encoder
#include <GxEPD2_BW.h>          //E-Ink Display
#include <Adafruit_NeoPixel.h>  //Digital RGB LEDs

//Keys
const byte nSW = 9;
const byte SW[] = {PIN_SW1, PIN_SW2, PIN_SW3, PIN_SW4, PIN_SW5, PIN_SW6, PIN_SW7, PIN_SW8, PIN_SW9}; //Array of switches for easy iteration
bool pressed[] = {false, false, false, false, false, false, false, false, false}; //Last state of each key to track changes
uint32_t swDebounce[] = {0L, 0L, 0L, 0L, 0L, 0L, 0L, 0L, 0L};

//Rotary encoder
Encoder rotary(PIN_ROTA, PIN_ROTB);
long rotaryPosition = 0;  //Last position to keep track of changes

//Display
GxEPD2_290 display(/*CS=*/ PIN_CS, /*DC=*/ PIN_DC, /*RST=*/ PIN_RST, /*BUSY=*/ PIN_BUSY);
// Alternative classes: GxEPD2_290_T94 (V2 of the display), GxEPD2_290_T94_V2 (V2 when partial updates do not work)

void initDisplay() {
  display.init(0, true, 2, false);
  display.writeScreenBuffer();
  display.refresh();
  display.writeScreenBufferAgain();
  display.powerOff();
}

void setup() {
  initLEDs();
  //Initialize LEDs first, for some reason they initialize blue
  //  after a power cycle which is pretty annoying.

  Serial.begin(115200);

  defaultAssignment();

  //Greeting on serial
  Serial.println("= InkKeys =");

  //Set pin modes for keys
  for (int i = 0; i < nSW; i++) {
    pinMode(SW[i], INPUT_PULLUP);
  }

  //Set rotary encoder to zero
  rotary.write(rotaryPosition);

  //Init e-ink screen, clear it and turn it off.
  initDisplay();

  //Init HID.
  //These three should provide most desired functions and as the 32u4
  //on the Pro Micro provides 6 endpoints (-1 for serial), we can
  //use the single report variants for compatibility.
  BootKeyboard.begin();
  BootMouse.begin();
  SingleConsumer.begin();

  //Show LED greeting to confirm completion
  ledGreeting(800);
  Serial.println("Ready.");
}

void loop() {
  checkKeysAndReportChanges();
  checkRotaryEncoderAndReportChanges();
  handleSerialInput();
}

//Called when state of key has changed. Checks debounce time
//and returns false if event should be filtered. Otherwise it
//returns true and resets the debounce timer.
bool debounce(byte i) {
  long t = millis();
  if (t - swDebounce[i] < DEBOUNCE_TIME)
    return false;
  else {
    swDebounce[i] = t;
    return true;
  }
}

//Check if keys have changed and report any changes
void checkKeysAndReportChanges() {
  for (int i = 0; i < nSW; i++) {
    int state = digitalRead(SW[i]);
    if (state == LOW && !pressed[i]) {
      if (debounce(i)) {
        pressed[i] = true;
        Serial.print(i+1);
        Serial.println("p");
        executeEvents(assignments[i][0]);
      }
    } else if (state == HIGH && pressed[i]) {
      if (debounce(i)) {
        pressed[i] = false;
        Serial.print(i+1);
        Serial.println("r");
        executeEvents(assignments[i][1]);
      }
    }
  }
}

//Check if rotary encoder position changed and report any changes
void checkRotaryEncoderAndReportChanges() {
  long rotaryNew = rotary.read();
  if (abs(rotaryNew - rotaryPosition) >= ROT_FACTOR) {
    int report = (rotaryNew-rotaryPosition)/ROT_FACTOR;
    Serial.print("R");
    Serial.println(report);
    rotaryPosition += report*ROT_FACTOR;
    for (int i = 0; i < report; i++)
      executeEvents(assignments[9][0]);
    for (int i = 0; i < -report; i++)
      executeEvents(assignments[9][1]);
  }
}

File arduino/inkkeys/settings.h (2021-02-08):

//Display
const byte PIN_DIN = 16;
const byte PIN_CLK = 15;
const byte PIN_CS = 19;
const byte PIN_DC = 18;
const byte PIN_RST = 14;
const byte PIN_BUSY = 10;

//Display size
const short DISP_W = 128; //Dispaly width
const short DISP_H = 296; //Display height

//LEDs
const byte PIN_LED = 20;
const byte N_LED = 12; //Number of LEDs

//Rotary encoder
const byte PIN_ROTA = 0;
const byte PIN_ROTB = 1;
const byte PIN_SW1 = 21;

const byte ROT_FACTOR = 4;         //Smallest reported step, typically one "click" on the encoder 
const byte ROT_CIRCLE_STEPS = 20;  //Rotary steps in a full circle

//Keys
const byte PIN_SW2 = 2;
const byte PIN_SW3 = 3;
const byte PIN_SW4 = 4;
const byte PIN_SW5 = 5;
const byte PIN_SW6 = 6;
const byte PIN_SW7 = 7;
const byte PIN_SW8 = 8;
const byte PIN_SW9 = 9;

const int DEBOUNCE_TIME = 50; //Debounce reject interval in milliseconds

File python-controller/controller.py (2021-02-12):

SERIALPORT = None #None = Auto-detect, to specify a specific serial port, you can set it to something like "/dev/ttyACM0" (Linux) or "COM1" (Windows)
VID = 0x1b4f      #USB Vendor ID for a Pro Micro
PID = 0x9206      #USB Product ID for a Pro Micro
DEBUG = False     #More output on the command line

from inkkeys import *        #Inkkeys module
from processchecks import *  #Functions to check for active processes and windows
from modes import *          #Definitions of the hotkey functions in different "modes"
from mqtt import InkkeysMqtt #A small class to encapsule MQTT specific functions. You will need to adapt this to your needs if you want to use this.

import time                         #Time functions
from serial import SerialException  #Serial functions
import serial.tools.list_ports      #Function to iterate over serial ports
import re                           #Regular expressions process name matching
import traceback                    #Print tracebacks if an error is thrown and caught

print("https://there.oughta.be/a/macro-keyboard")
print('I will try to stay connected. Press Ctrl+c to quit.')

############################################################################################################

#This is the main part, which reassigns keys, sets the content of the display and updates the LEDs.
#The logic of this is built around "modes". The modes themselves are defined in "modes.py", where you can
#change key assignments, images, LED animations and their entire logic.

#Below, you only define a list of modes (defined in "modes.py") that are active and set either a process
#(mode would be active whenever the process runs) or an active window (mode is active if the window has
#the focus. The latter is a compiled regular expression pattern. Mode priority corresponds to the order in the
#list, so the first mode with a matching process or active window will be activated.

mqtt = InkkeysMqtt("192.168.2.5", DEBUG) #Set address to "None" if you do not want to use mqtt

modes = [\
            {"mode": ModeOBS(), "process": "obs"}, \
            {"mode": ModeBlender(), "activeWindow": re.compile("^Blender")}, \
            {"mode": ModeGimp(), "activeWindow": re.compile("^gimp.*")}, \
            {"mode": ModeFallback(mqtt)} \
        ]

############################################################################################################

# Usually there should not be anything to be customized below this point

############################################################################################################

#If we found the device, successfully connected and retreived its information, we enter this work function,
#which primarily consists of an infinite loop that only returns if we hit Ctrl+C (or kill the process).

def work():
    mode = None             #Current mode of the device (i.e. key mappings for specific process).
    pollInterval = 0        #Polling interval as requested by the module when the last call to "poll" was made
    lastPoll = 0            #Keeps track of the last time the poll function of the mode instance was called
    lastProcessList = 0     #Keeps track of the last time the list of processes was retrieved
    lastModeCheck = 0       #Keeps track of the last time the current window was checked and a decision about the mode was made
    mqtt.connect()          #Connect to the MQTT server (if used)
    try:
        while True:     #Now we are in our main, infinite loop -------------------
            now = time.time() #Time of this iteration

            if now - lastProcessList > 5.0:      # Only check the process list every 5 seconds.
                processes = getActiveProcesses() # This is a surprisingly expensive and slow call, so don't overdo as it might prevent smooth LED animation (fixable by implementing a second thread) and burn more CPU resources than you might want from a background process
                lastProcessList = now

            if now - lastModeCheck > 0.5:       # Check active window and decide which mode to use. This can be done more regularly, but since the e-ink screen takes a moment to update, it does not make sense to check more frequently
                window = getActiveWindow()      # Get the currently active window
                if window != None:              # Sometime getting the active window fails, then ignore it. (Some window managers allow having no window in focus)
                    activeWindow = window
                    if DEBUG:                   #Enable DEBUG to see the actual name of the current window if you need it to match your modules
                        print("Active window: " + str(activeWindow))

                for i in modes:                 #Iterate over modes and use the first one that matches
                    if ("process" in i and i["process"] in processes) or ("activeWindow" in i and i["activeWindow"].match(activeWindow)) or not ("process" in i or "activeWindow" in i):
                        #Either the process for this mode is running or the active window matches the regular expression. This is the mode we will set now.
                        if i["mode"] != mode:           # Do not set the mode again if we already have this one
                            if mode != None:            
                                mode.deactivate(device) # If there was a previous mode, call its deactivate function
                            mode = i["mode"]            # Set new mode
                            mode.activate(device)       # ...and call its activate function
                            pollInterval = 0            # Reset the poll intervall to call mode.poll() at least once (see below)
                        break
                lastModeCheck = now

            if pollInterval >= 0 and now - lastPoll > pollInterval:    #Regularly call the poll function of the mode if it requires regular polling
                #The poll function returns the desired interval when it should be called next - or False if polling is not required in this mode
                pollInterval = mode.poll(device)
                lastPoll = now

            #Now for the functions that need to be called very often and fast:
            mode.animate(device)    #Used for LED animations
            device.poll()           #Required for the callbacks that are associated with key presses reported via serial

            #If the actions so far did take less than 1/30 seconds, sleep until 1/30s have passed as there is no need to exceed 30fps
            timeTo30fps = time.time() - now + 0.0333
            if timeTo30fps > 0:
                time.sleep(timeTo30fps)
                    #End of main loop -------------------------------------------


    except KeyboardInterrupt:       #User pressed Ctrl+c
        mqtt.disconnect()
        print('Disconnected from device. Hit Ctrl+c again to quit before reconnect.')
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

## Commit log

2021-02-08 Initial commit, preparing for publication.
    [bottom.stl, debug-plug.stl, inkkeys.kicad_pcb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]
2021-02-12 Fix: Polling, better serial input, memory leak / slowdown after many window requests.
    [controller.py, device.py, processchecks.py]
2021-02-20 Added the blend file from which the STL files were exported.
2021-05-27 Added know with finger dimple by Roland Irving.
2026-10-13 Write repeated images to both display buffers after a refresh
    The controller sends every image a second time after a partial refresh,
    which suits revision 1 (IL3820, it swaps its buffers after an update),
    where writing to the current buffer again is enough.
    Revision 2 (SSD1680, GxEPD2_290_T94/_T94_V2) does not swap. It compares
    the "current" and "previous" buffers on a partial refresh and only fully
    drives pixels that differ. The repeat went to the current buffer, so the
    previous buffer kept stale data: pixels that should turn white got only a
    short touch-up pulse and stayed grey, leaving ghosts of earlier images
    (#16, #14).
    The repeated transfer is now marked with a trailing " a" (D x y w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
2026-10-13 Add a partial refresh waveform for revision 2 displays
    With GxEPD2_290_T94_V2, partial refreshes on revision 2 still leave grey
    traces and fade unchanged black areas (a black title banner turns light
    grey within a few mode switches):
    - GxEPD2 loads only the waveform table for partial refreshes, not the gate
    and source voltages, VCOM and end option that Waveshare's reference
    driver (epd2in9_V2) sets with it. Those are now set before every partial
    refresh.
    - While changed pixels are driven, unchanged ones sit slightly off VCOM and
    black pixels drift towards white. The stock table only gives them one
    frame to recover at the end. The new table adds a 2-frame "stay black"
    phase to ev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
